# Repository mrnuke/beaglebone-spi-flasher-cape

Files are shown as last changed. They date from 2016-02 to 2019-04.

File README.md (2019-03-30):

# SPI flasher cape for Beaglebone family

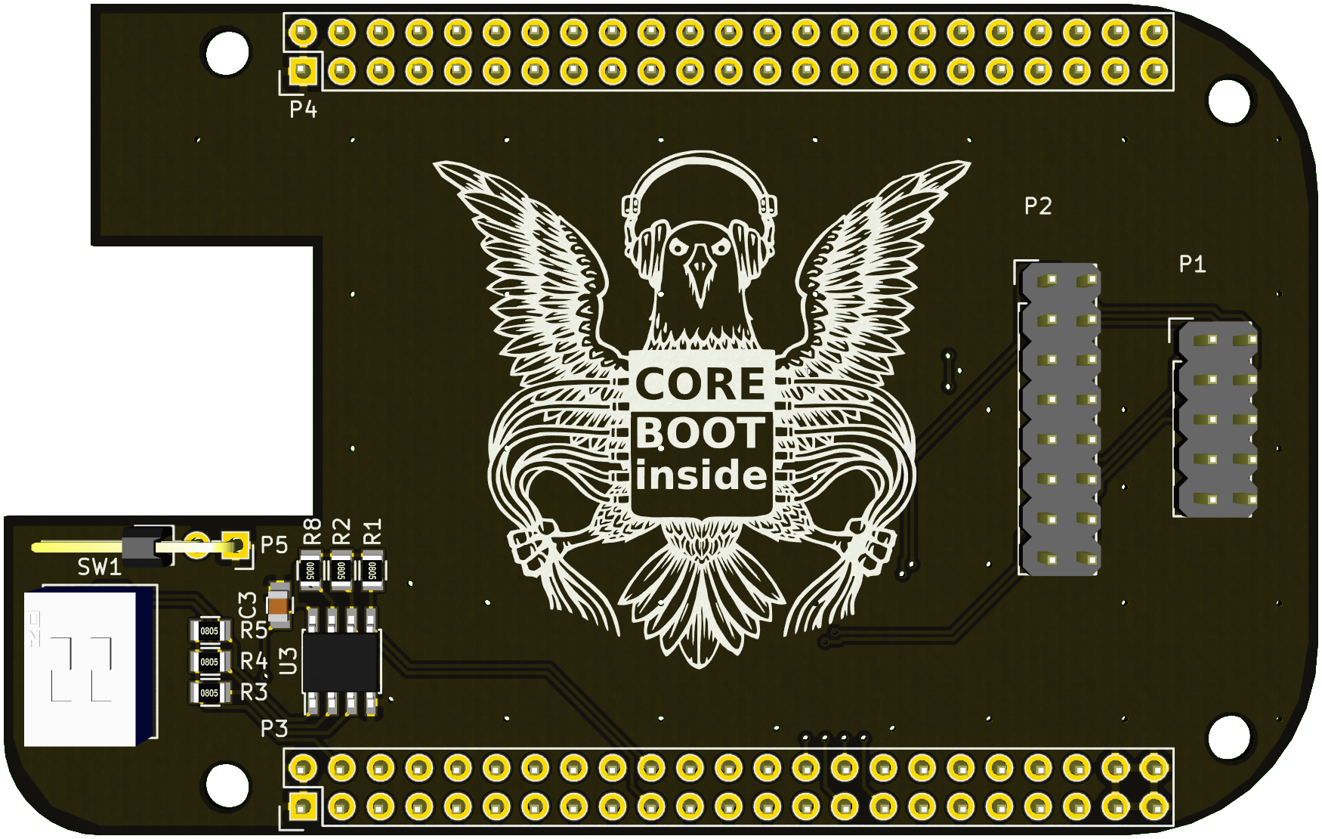
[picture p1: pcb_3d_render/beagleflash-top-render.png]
Cape rendering, top side

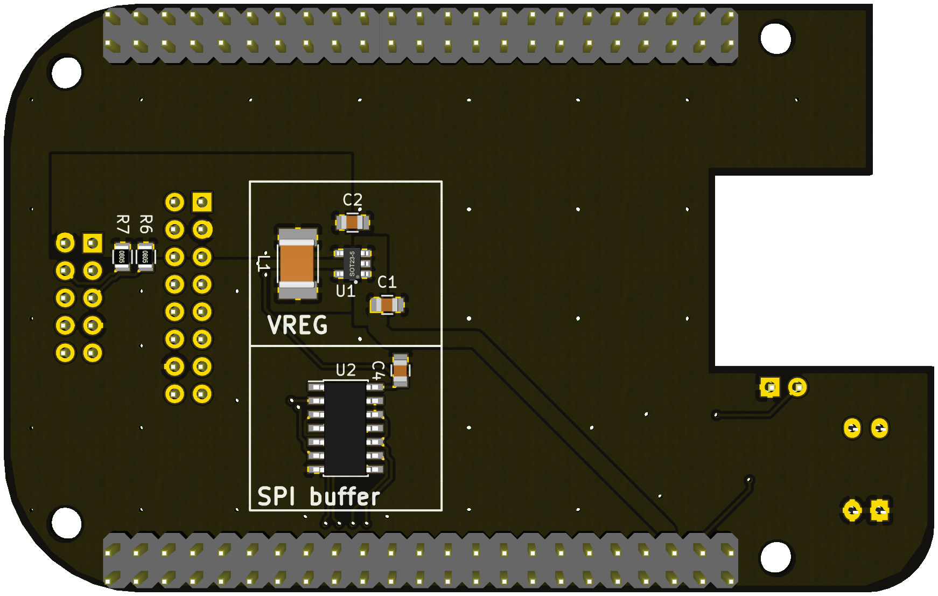
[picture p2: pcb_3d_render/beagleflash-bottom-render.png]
Cape rendering, bottom side


## Introduction

The SPI flasher cape is a cape for the BeagleBone family of boards which
allows the BeagleBone to interface with a SPI NOR flash chip in order to allow
programming or reading the chip's contents.

### Features

#### Low BOM cost

The total bill-of-materials (COM) cost is under $10 US, including the PCB.

#### Independent voltage regulator

The independent voltage regulator (VR) supplies the power for the operation of
the SPI chip, and is independent of te BeagleBone's internal voltage rails.
This protects the BeagleBone from brown-outs inc case of an external
short-circuits. Since it is a switching regulator, the VR dissipates very
little power when compared to more common linear regulators.

#### SPI buffer IC

The SPI buffer IC protects the internal pins of the BeagleBone from ESD and
short-circuits. The buffer IC is powered from the independent VR, and prevents
excessive currents from being sourced by the BeagleBone's processor in case of
short-circuits.

The buffer IC is driven by the CS signal of the SPI interface, which means that
the outputs are high-impedance when no SPI communication is taking place. As a
result, the SPI chip does not have to be disconnected when the target system is
powered on. Also, since the buffer is enabled by the CS signal, there is no
extra software configuration that needs to be done before enabling the signal
path to the SPI chip, as there is on other solutions (e.g. Gogole servo board).
It's all automatic!

#### Integrated Cape EEPROM

The integrated EEPROM informs the BeagleBone what pins are used by the cape, so
the cape is automatically detected, and the interfaces pins are automatically
configured.

#### Industry-standard headers for 8-pin and 16-pin SPI devices

The external pin headers match the pinout of 8-pin and 16-pin SPI flash parts
so that programming clips (e.g. Pomona SOIC-8) may be directly connected to the
cape.

#### Integrated pull-up resistors for HOLD and WP lines

The integrated pull-up resistors ensure that the HOLD and WP lines of the SPI
chip are driven appropriately. This allows "naked" chips to be programmed. For
mounted SPI chips, the pull-ups prevent short-circuits if another component on
the target system drives these signals low.

## Layout of the repository

### kicad/

This folder contains the KiCad schematic and board files

* beagleflash-cache.lib:
	project-specific chematic symbol library
* beagleflash.kicad_pcb:
	KiCad (pcbnew) PCB design file
* beagleflash.net:
	Netlist file with footprint associactions
* beagleflash.pro:
	KiCad project file
* beagleflash.sch:
	KiCad (eeschema) schematic

### gerbers/

* beagleflash-B.Cu.gbl:
	Bottom copper layer
* beagleflash-B.Mask.gbs:
	Bottom soldermask layer
* beagleflash-B.SilkS.gbo:
	Bottom silkscreen layer
* beagleflash-Edge.Cuts.gm1:
	Board outline
* beagleflash-F.Cu.gtl:
	Top copper layer
* beagleflash-F.Mask.gts:
	Top soldermask layer
* beagleflash-F.SilkS.gto:
	Top silkscreen layer
* beagleflash.txt:
	Drill file

### pcb_3d_render/

3D renderings of the PCB.

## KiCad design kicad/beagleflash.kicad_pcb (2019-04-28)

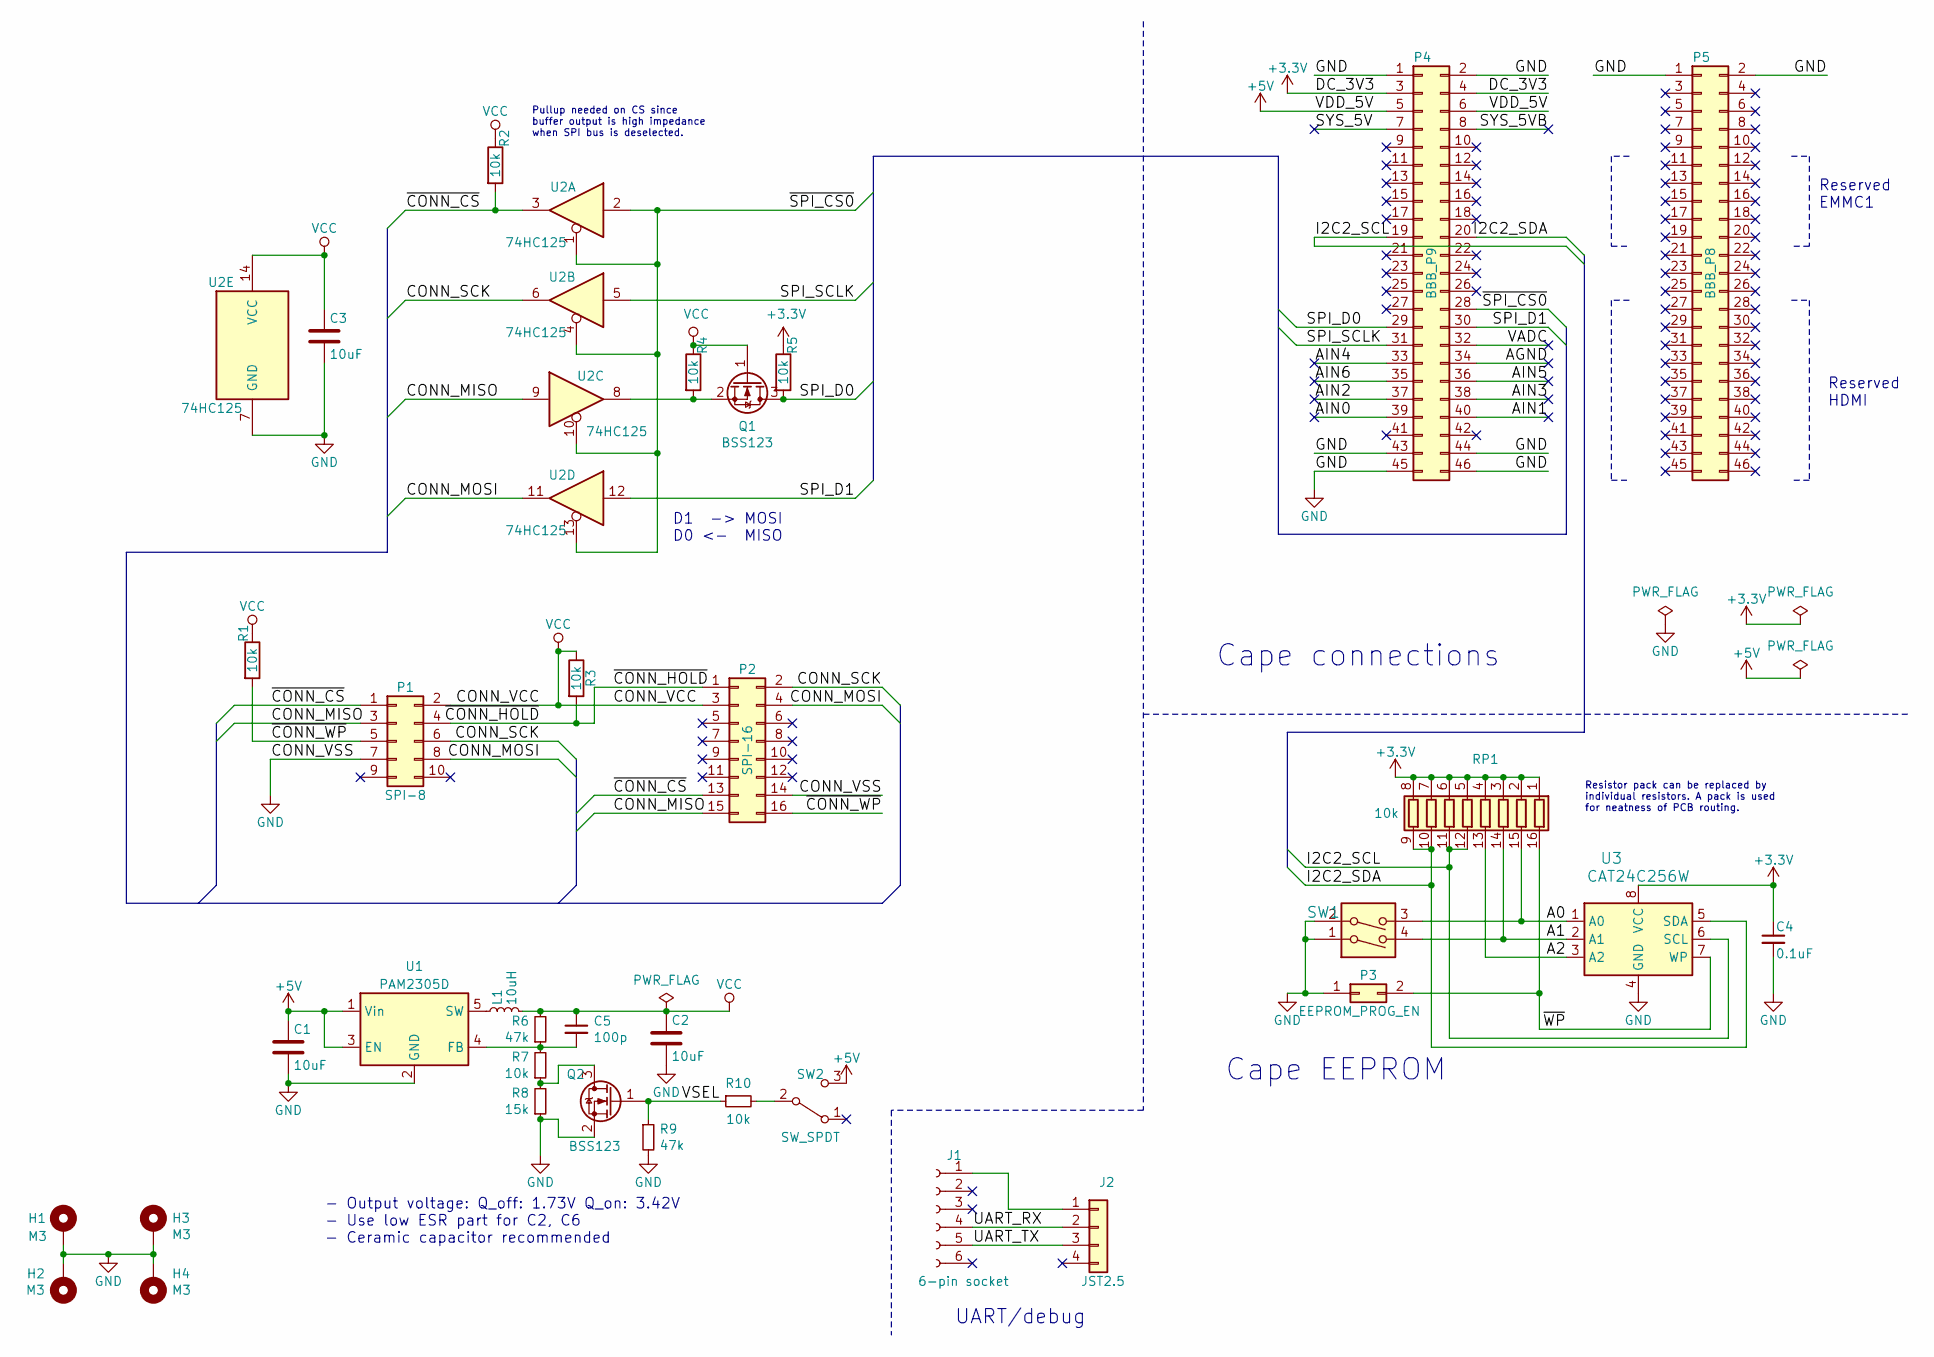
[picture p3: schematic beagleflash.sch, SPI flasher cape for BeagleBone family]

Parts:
C1, C2, C3: 10uF; C_0805_2012Metric
C4: 0.1uF; C_0805_2012Metric
C5: 100p; C_0805_2012Metric
H1, H2, H3, H4: M3; MountingHole_3.2mm_M3_ISO14580_Pad
J1: 6-pin socket; PinHeader_1x06_P2.54mm_Vertical
J2: JST2.5; JST_XH_B04B-XH-A_1x04_P2.50mm_Vertical
L1: 10uH; L_1812_4532Metric
P1: SPI-8; IDC-Header_2x05_P2.54mm_Vertical
P2: SPI-16; IDC-Header_2x08_P2.54mm_Vertical
P3: EEPROM_PROG_EN; PinHeader_2x01_P2.54mm_Horizontal
P4: BBB_P9; PinHeader_2x23_P2.54mm_Vertical
P5: BBB_P8; PinHeader_2x23_P2.54mm_Vertical
Q1, Q2: BSS123; SOT-23
R1, R2, R3, R4, R5, R7, R10: 10k; R_0805_2012Metric
R6, R9: 47k; R_0805_2012Metric
R8: 15k; R_0805_2012Metric
RP1: 10k; SOIC-16_3.9x9.9mm_P1.27mm
SW1: DIPS_02; SW_DIP_SPSTx02_Slide_9.78x7.26mm_W7.62mm_P2.54mm
SW2: SW_SPDT; PinHeader_1x03_P2.54mm_Horizontal
U1: PAM2305D; TSOT-23-5
U2: 74HC125; SOIC-14_3.9x8.7mm_P1.27mm
U3: CAT24C256W; SOIC-8_3.9x4.9mm_P1.27mm

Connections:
+3V3: C4.1, P4.3, P4.4, R5.1, RP1.1 (R1.1), RP1.2 (R2.1), RP1.3 (R3.1), RP1.4 (R4.1), RP1.5 (R5.1), RP1.6 (R6.1), RP1.7 (R7.1), RP1.8 (R8.1), U3.8 (VCC)
+5V: C1.1, P4.5, P4.6, SW2.3 (C), U1.1 (Vin), U1.3 (EN)
/A0: RP1.15 (R2.2), SW1.3, U3.1 (A0)
/A1: RP1.14 (R3.2), SW1.4, U3.2 (A1)
/A2: RP1.13 (R4.2), U3.3 (A2)
/AGND: P4.34
/AIN0: P4.39
/AIN1: P4.40
/AIN2: P4.37
/AIN3: P4.38
/AIN4: P4.33
/AIN5: P4.36
/AIN6: P4.35
/CONN_MISO: P1.3, P2.15, U2.9
/CONN_MOSI: P1.8, P2.4, U2.11
/CONN_SCK: P1.6, P2.2, U2.6
/I2C2_SCL: P4.19, RP1.11 (R6.2), RP1.12 (R5.2), U3.6 (SCL)
/I2C2_SDA: P4.20, RP1.9 (R8.2), RP1.10 (R7.2), U3.5 (SDA)
/SPI_D0: P4.29, Q1.3 (D), R5.2
/SPI_D1: P4.30, U2.12
/SPI_SCLK: P4.31, U2.5
/SYS_5V: P4.7
/SYS_5VB: P4.8
/UART_RX: J1.4, J2.2
/UART_TX: J1.5, J2.3
/VADC: P4.32
/VSEL: Q2.1 (G), R9.1, R10.1
/~CONN_CS: P1.1, P2.13, R2.2, U2.3
/~CONN_HOLD: P1.4, P2.1, R3.2
/~CONN_WP: P1.5, P2.16, R1.2
/~SPI_CS0: P4.28, U2.1, U2.2, U2.4, U2.10, U2.13
/~WP: P3.2, RP1.16 (R1.2), U3.7 (WP)
GND: C1.2, C2.2, C3.2, C4.2, H1.1, H2.1, H3.1, H4.1, P1.7, P2.14, P3.1, P4.1, P4.2, P4.43, P4.44, P4.45, P4.46, P5.1, P5.2, Q2.2 (S), R8.1, R9.2, SW1.1, SW1.2, U1.2 (GND), U2.7 (GND), U3.4 (GND)
unnamed: C5.2, R6.1, R7.2, U1.4 (FB)
unnamed: J1.1, J2.1
unnamed: L1.1, U1.5 (SW)
unnamed: Q1.2 (S), R4.2, U2.8
unnamed: Q2.3 (D), R7.1, R8.2
unnamed: R10.2, SW2.2 (B)
VCC: C2.1, C3.1, C5.1, L1.2, P1.2, P2.3, Q1.1 (G), R1.1, R2.1, R3.1, R4.1, R6.2, U2.14 (VCC)

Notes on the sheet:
Reserved EMMC1
Reserved HDMI
Cape EEPROM
Cape connections
- Output voltage: Q_off: 1.73V Q_on: 3.42V - Use low ESR part for C2, C6 - Ceramic capacitor recommended
D1 -> MOSI D0 <- MISO
Pullup needed on CS since buffer output is high impedance when SPI bus is deselected.
Resistor pack can be replaced by individual resistors. A pack is used for neatness of PCB routing.
UART/debug

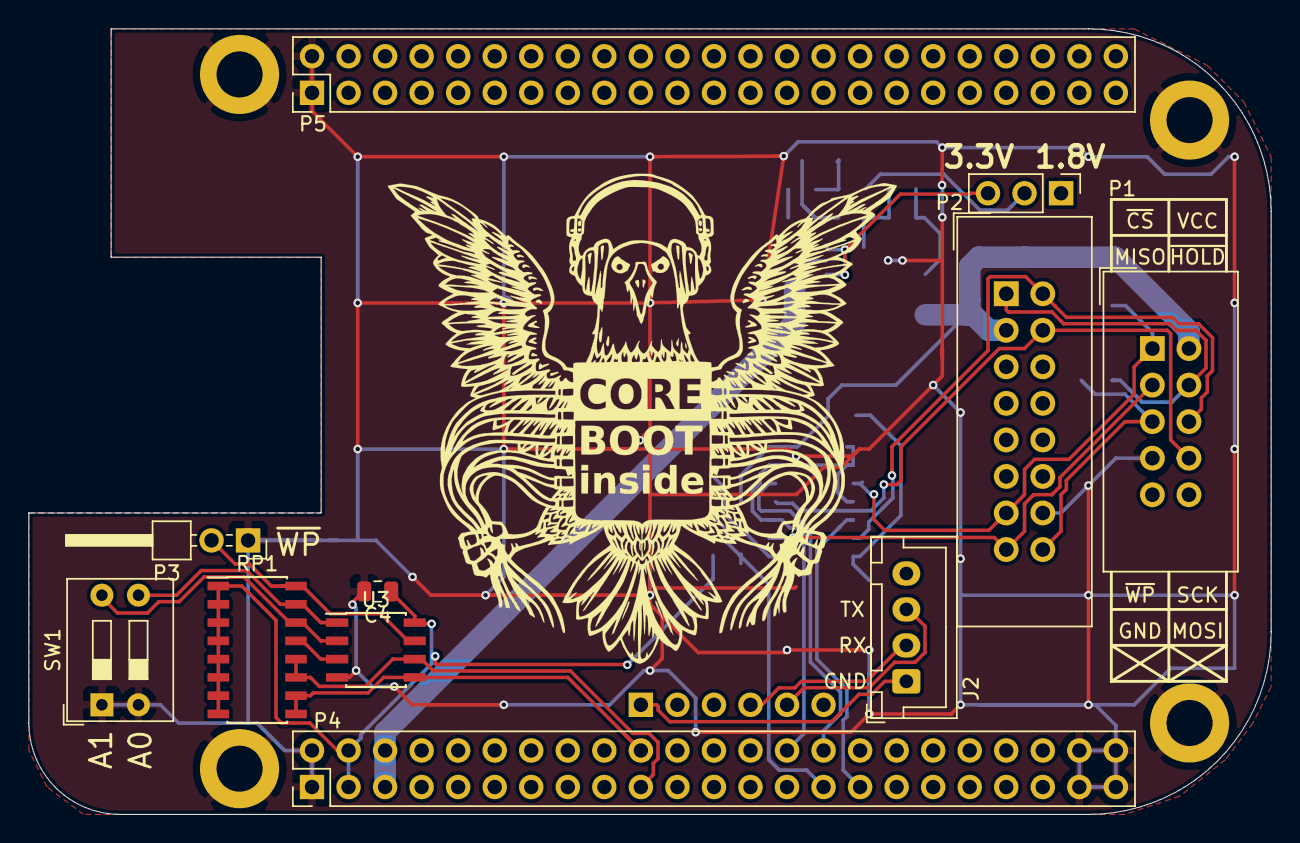
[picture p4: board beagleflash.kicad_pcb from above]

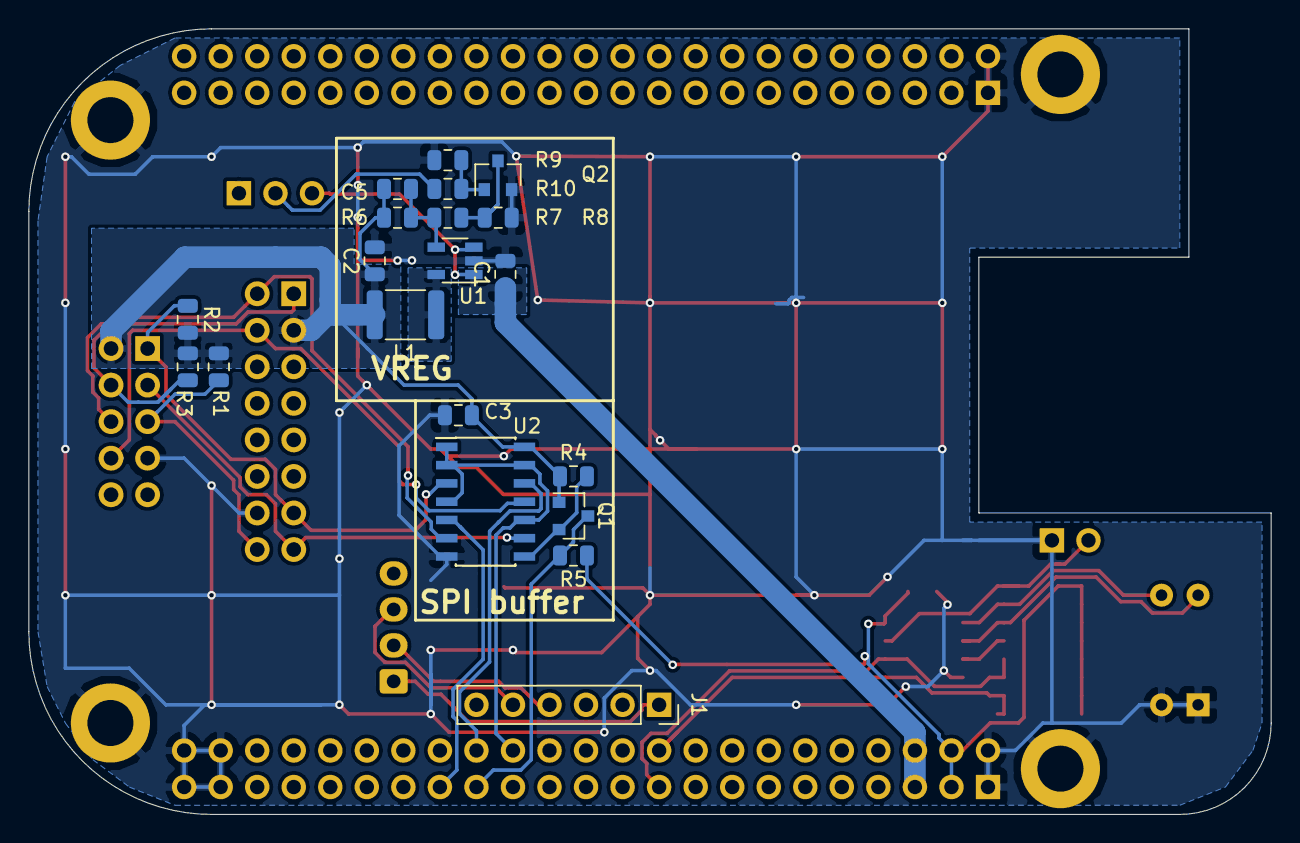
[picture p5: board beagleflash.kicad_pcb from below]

Board: 2 copper layers, 86.4 x 54.6 mm, 36 parts (20 on the bottom side), 29 nets.

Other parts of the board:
G1: Logo_Open_Hardware_Small; logo-coreboot

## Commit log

2016-02-04 Add schematic and design files for revision 0.1 of PCB
    This is the beginning, folks! Prototype PCBs are on order.
    [beagleflash.kicad_pcb, beagleflash.sch]
2016-02-04 Add rendering of Rev 0.1 PCBs
    These prototype PCBs are on order. Only computer-generated renderings
    are available at this time.
2016-02-04 Add gerber files for revision 0.1 PCB
    These are the production files that were sent to the manufacturing
    house for the Rev 0.1 of the PCB.
    [beagleflash-B.Cu.gbl, beagleflash-B.Mask.gbs, beagleflash-B.SilkS.gbo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]
2016-10-14 Add .gitignore files
    It's safe to ignore imtermediate files, backup files, backupos to backups
    and so forth, that KiCAD creates.
2016-10-14 kicad: Move logo into stand-alone footprint library
    Otherwise it can easily get lost. This creates a new footprint library
    where all the cape-specific projects will go.
2016-10-14 kicad: Add Revision 0.2 of beagleflash
    Previous revision did not work because the MOSI and MISO pins were
    swapped before the buffer. That's now fixed. Other changes include:
    - Replaced individual resistors around EEPROM with resistor array
    - Added silkscreen designators for SPI pinout on 10-pin header
    - Re-organized DC-DC regulator to have shorter current loops
    - Added exposed GND copper around mounting holes.
    [beagleflash.kicad_pcb, beagleflash.sch]
2019-03-30 kicad: Update schematic to use KiCAD 5 symbol library
    A lot has changed in kicad since beagleflash was originally designed.
    KiCAD has a new library format, and it's preferrable to move all the
    symbols to the new format before making any design improvements.
    The is now a symbol for mounting holes with electrical connection:
    * Change mounting hole symbol from connector to MountingHole_Pad.
    [beagleflash.sch]
2019-03-30 kicad: Use the KIPROMOD macro instead of hardcoding library path
2019-04-27 kicad: Add revision 0.3 schematic
    Two incremental changes from rev 0.2:
    * Bring out debug UART to separate header
    * Add 1.8V programming option
    Debug UART:
    Sometimes, it may become necessarry to connect a debug UART to recover
    a bricked beaglebone. Being able to do this without removing the cape
    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
    [beagleflash.sch]
2019-04-28 kicad: Add revision 0.3 layout
    [beagleflash.kicad_pcb]

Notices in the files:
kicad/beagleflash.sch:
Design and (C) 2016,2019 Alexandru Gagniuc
